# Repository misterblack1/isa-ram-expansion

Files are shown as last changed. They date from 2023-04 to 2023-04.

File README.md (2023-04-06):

# 8-bit ISA RAM expansion board with UMB support

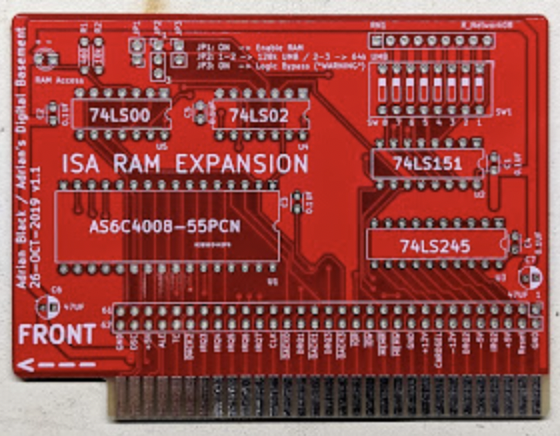
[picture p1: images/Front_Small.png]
PCB Front


This is my simple 8-bit ISA RAM expansion board. I created it to allow me to add UMB memory to a regular XT. It can also bring a 512k or 256k XT up to a full 640k.

- It is simple and easy to build.
- PCB is small so it is inexpensive to have produced.
- No drivers needed. (For conventional memory support)
- Desienged with KiCad, files available here. Free to modify.
- This card only supports conventional memory, no EMS. Extra RAM can be mapped into the high memory space (above 640k) allowing for UMB on XT machines.
- Required parts to build are marked on the PCB silk screen and on the schematic. (Sorry no BOM)

To access UBM, there are various DOS utilities to do this. I have a set of them uploaded in this REPO:
https://github.com/misterblack1/tandy1000ex-hx-ram/tree/master/umb_dos_utils

This card has 512k of 8-bit RAM on it. Therefore, you can map that 512k into the 8088 address space in 128k chunks. (Four chunks.) Use the DIP switches to select which banks are mapped by disabling the extra RAM on the ISA card. Even though you can map the 512k into all of the 1024k of address space in the 8088, please remember the mapping repeats once.

If you imagine the 512k chip is broken up into 4 banks of 128 k. A, B, C and D:

- A -> 0-128k (Lower)
- B -> 128k-256k (Lower)
- C -> 256k-320k (Lower)
- D -> 320k-512k (Lower)
- A -> 512k-640k (Upper)
- B -> 640k-768k (Upper)
- C -> 768k-897k (Upper)
- D -> 869-1024k (Upper)

So when configuring the card to map the 512k RAM into the system memory, you can only use any given bank on time. (Lower OR upper.) So, if you are using lower bank C and D to bring a PC from 256k to 512k total system RAM, you cannot use the upper bank C and D because they are already being used. If you do, the system will crash.

Example:

PC has 256k of RAM installed on the motherboard. This motherboard RAM wil exist from 0k to 256k. 
You want this ISA card to bring the system to 640k conventional. 

Memory map would look like this:

- A -> 0-128k Motherboard
- B -> 128k-256k Motherboard
- C -> 256k-320k ISA RAM card
- D -> 320k-512k ISA RAM card
- A -> 512k-640k ISA RAM card
- B -> 640k-768k used by CGA/MDA card
- C -> 768k-897k Unused
- D -> 869-1024k Unused and System ROMs

So to configure the card, you must configure the DIP switches to disable the ISA RAM card mapping into lower A and B and upper B and D. That way it does not overlap these parts of the system.

Set SW1, SW2, SW6, SW7 and SW8 to ON. The rest should be off. If you try to add UMB memory to upper bank C (768k to 897k) this will not work and cause a crash because you are already using lower bank C to expand from 256k to 320k. The only unused bank on this card would be B -- but you cannot use it for UMB because the 640k-768k range is typically used by the video card. (MDA, CDA, etc.)

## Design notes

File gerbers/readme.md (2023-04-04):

Gerber files to have PCB made with any manufacturer

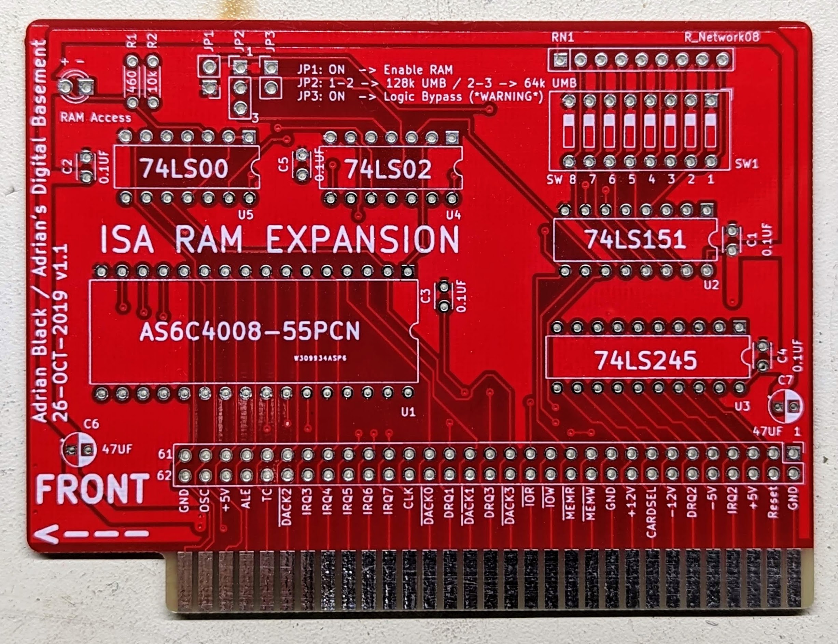
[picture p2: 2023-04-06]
images/PCB_Front.jpg

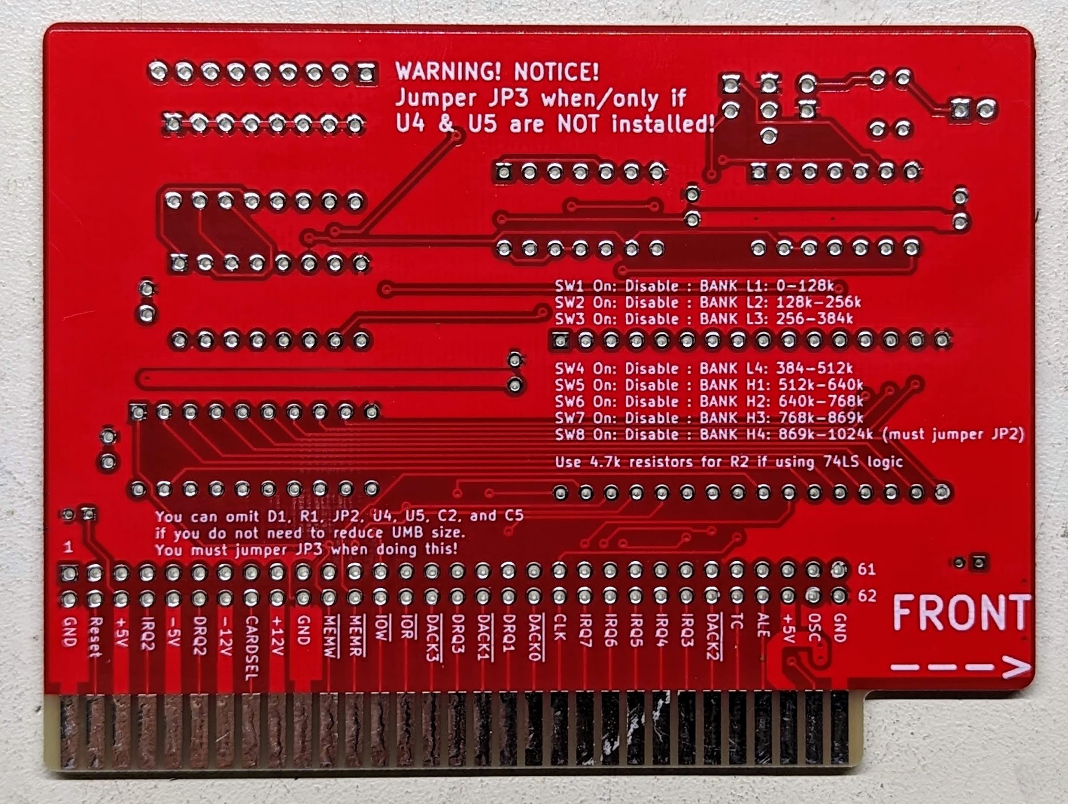
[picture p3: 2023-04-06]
images/PCB_Back.jpg

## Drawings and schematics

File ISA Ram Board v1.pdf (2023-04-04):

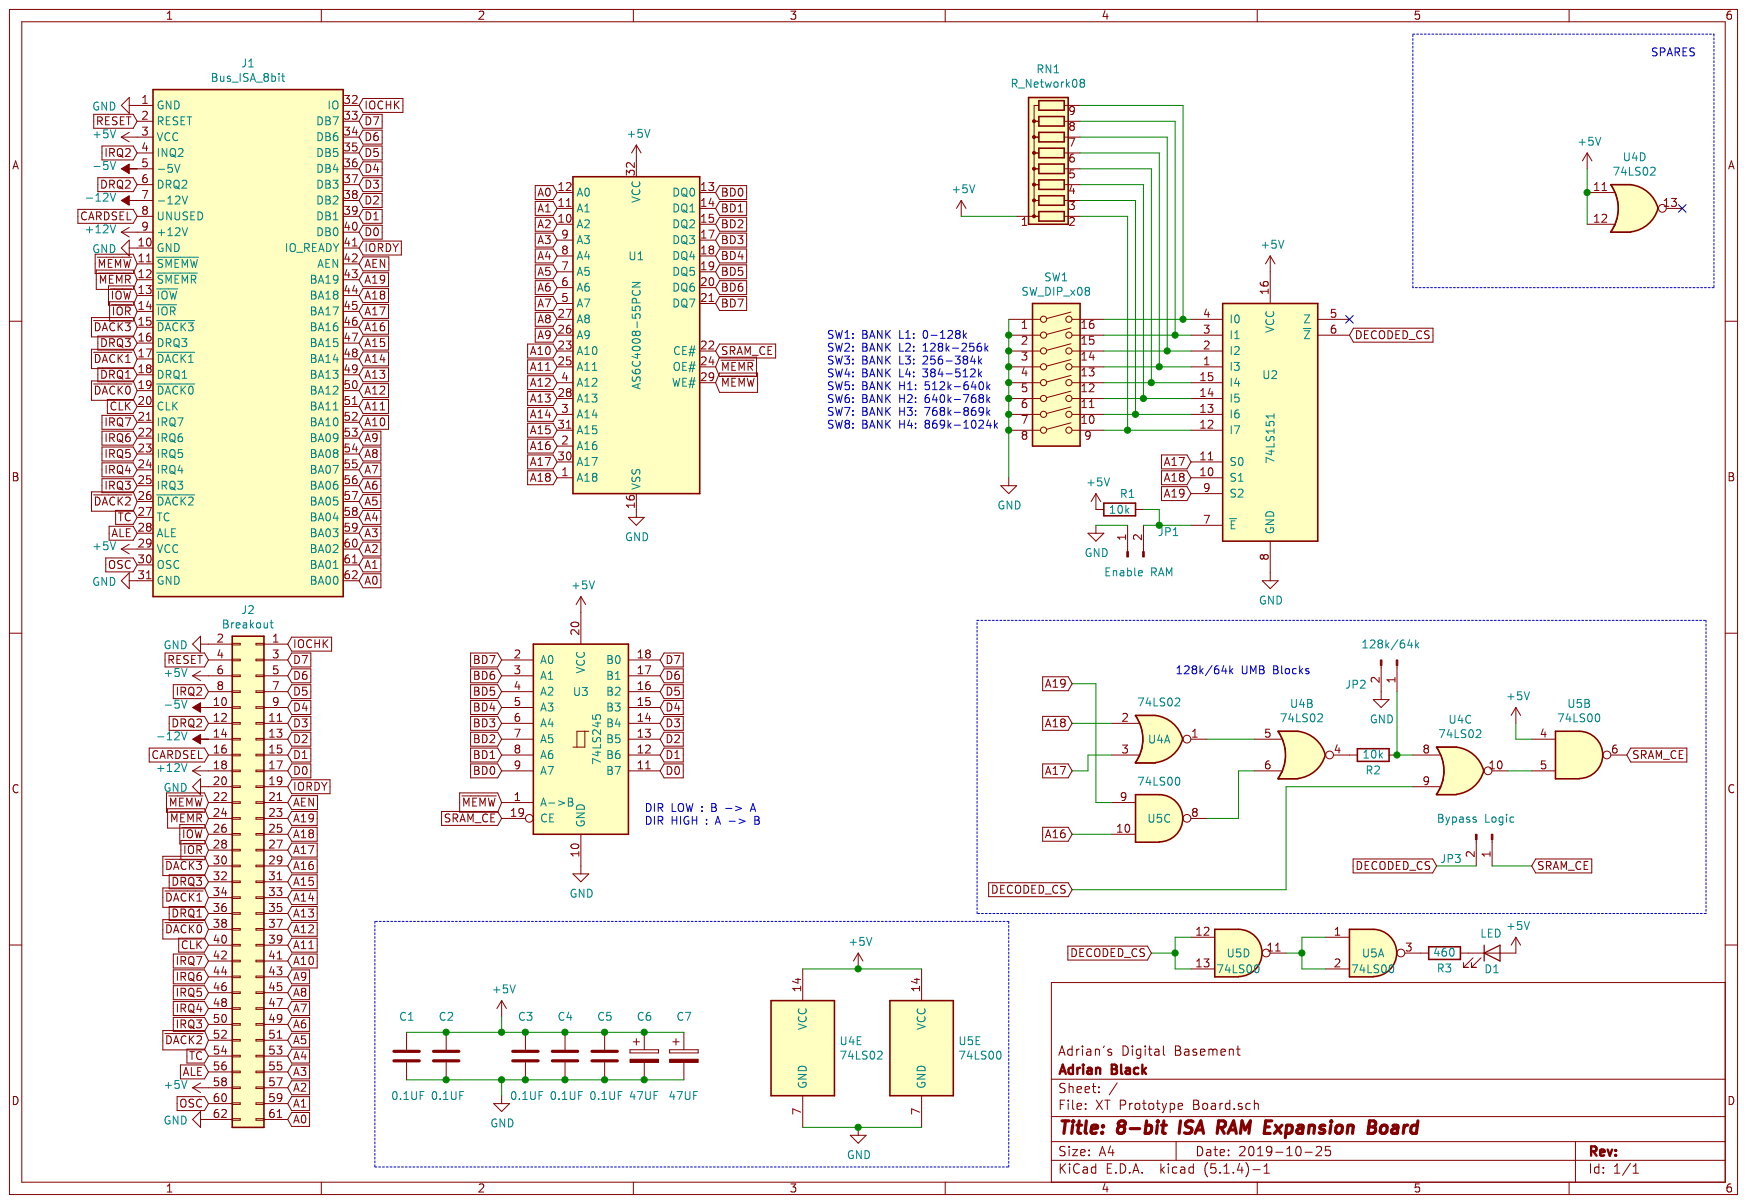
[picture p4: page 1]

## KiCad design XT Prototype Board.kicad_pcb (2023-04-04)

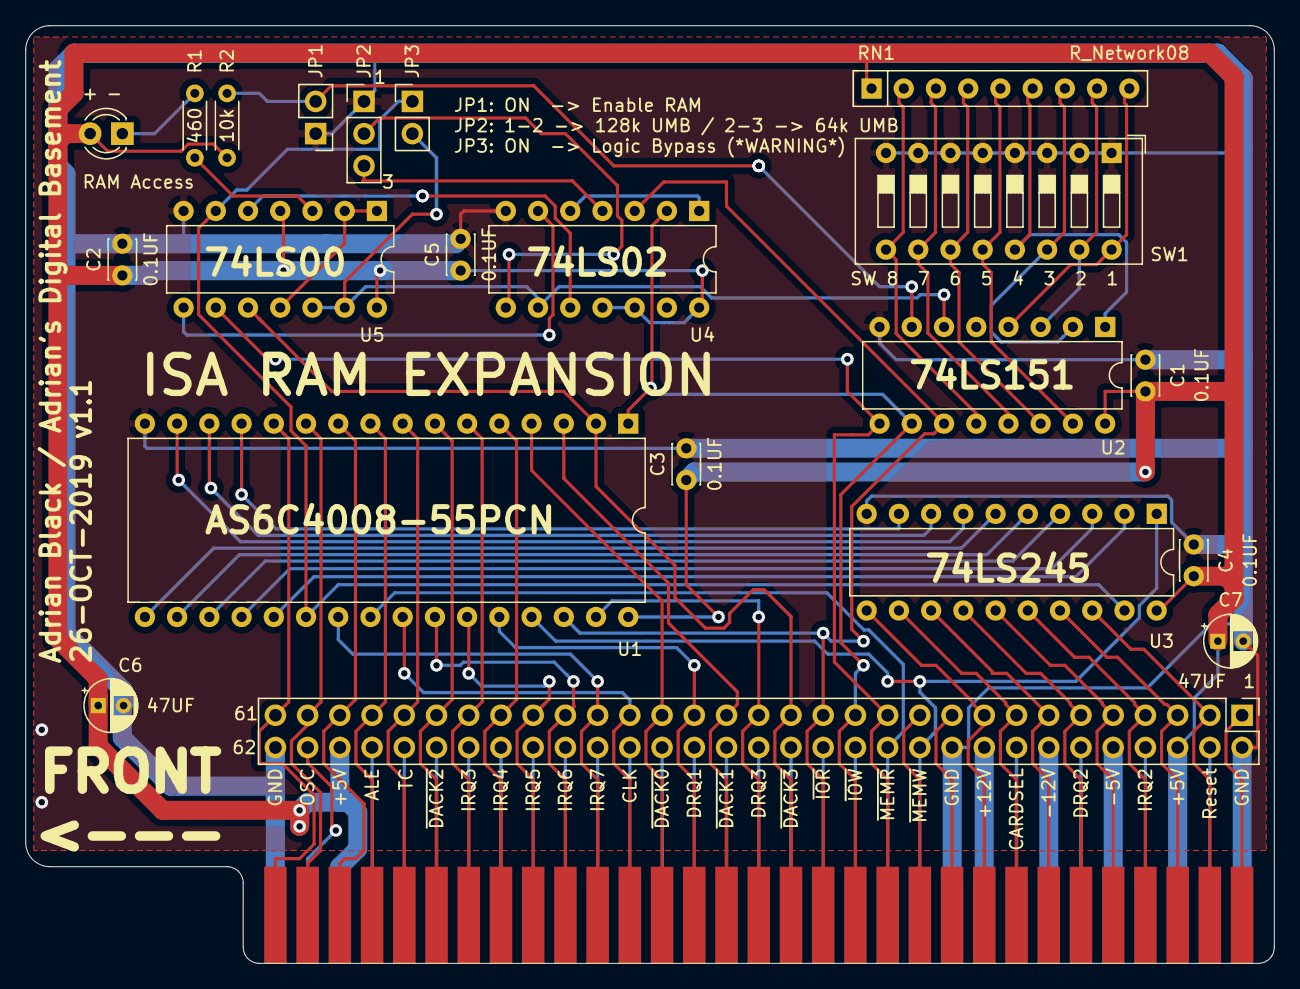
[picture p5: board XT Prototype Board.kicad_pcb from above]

Board: 2 copper layers, 98.4 x 73.9 mm, 22 parts (0 on the bottom side), 86 nets.

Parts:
C1, C2, C3, C4, C5: 0.1UF; C_Disc_D3.0mm_W2.0mm_P2.50mm
C6, C7: 47UF; CP_Radial_D4.0mm_P2.00mm
J1: Bus_ISA_8bit; Conn_Edge_PCB_ISA8
J2: Breakout; PinHeader_2x31_P2.54mm_Vertical
JP1: Enable RAM; PinHeader_1x02_P2.54mm_Vertical
JP2: 128k / 64k UMB; PinHeader_1x03_P2.54mm_Vertical
JP3: Bypass Logic; PinHeader_1x02_P2.54mm_Vertical
R1: 460; R_Axial_DIN0204_L3.6mm_D1.6mm_P5.08mm_Horizontal
R2: 10k; R_Axial_DIN0204_L3.6mm_D1.6mm_P5.08mm_Horizontal
RAM Access: LED; LED_D3.0mm
RN1: R_Network08; R_Array_SIP9
SW1: SW_DIP_x08; SW_DIP_SPSTx08_Slide_9.78x22.5mm_W7.62mm_P2.54mm
U1: AS6C4008-55PCN; DIP-32_W15.24mm
U2: 74LS151; DIP-16_W7.62mm
U3: 74LS245; DIP-20_W7.62mm
U4: 74LS02; DIP-14_W7.62mm
U5: 74LS00; DIP-14_W7.62mm

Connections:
+5V: C1.1, C2.1, C3.1, C4.1, C5.1, C6.1, C7.1, J1.3, J1.29, J2.6, J2.58, R2.2, RAM Access.2, RN1.1, U1.32, U2.16, U3.20, U4.11, U4.12, U4.14, U5.4, U5.14
+12V: J1.9, J2.18
-5V: J1.5, J2.10
-12V: J1.7, J2.14
A0: J1.62, J2.61, U1.12
A1: J1.61, J2.59, U1.11
A2: J1.60, J2.57, U1.10
A3: J1.59, J2.55, U1.9
A4: J1.58, J2.53, U1.8
A5: J1.57, J2.51, U1.7
A6: J1.56, J2.49, U1.6
A7: J1.55, J2.47, U1.5
A8: J1.54, J2.45, U1.27
A9: J1.53, J2.43, U1.26
A10: J1.52, J2.41, U1.23
A11: J1.51, J2.39, U1.25
A12: J1.50, J2.37, U1.4
A13: J1.49, J2.35, U1.28
A14: J1.48, J2.33, U1.3
A15: J1.47, J2.31, U1.31
A16: J1.46, J2.29, U1.2, U5.10
A17: J1.45, J2.27, U1.30, U2.11, U4.3
A18: J1.44, J2.25, U1.1, U2.10, U4.2
A19: J1.43, J2.23, U2.9, U5.9
AEN: J1.42, J2.21
ALE: J1.28, J2.56
BD0: U1.13, U3.9
BD1: U1.14, U3.8
BD2: U1.15, U3.7
BD3: U1.17, U3.6
BD4: U1.18, U3.5
BD5: U1.19, U3.4
BD6: U1.20, U3.3
BD7: U1.21, U3.2
CARDSEL: J1.8, J2.16
CLK: J1.20, J2.40
D0: J1.40, J2.17, U3.11
D1: J1.39, J2.15, U3.12
D2: J1.38, J2.13, U3.13
D3: J1.37, J2.11, U3.14
D4: J1.36, J2.9, U3.15
D5: J1.35, J2.7, U3.16
D6: J1.34, J2.5, U3.17
D7: J1.33, J2.3, U3.18
DECODED_CS: JP3.2, U2.6, U4.9, U5.12, U5.13
DRQ1: J1.18, J2.36
DRQ2: J1.6, J2.12
DRQ3: J1.16, J2.32
GND: C1.2, C2.2, C3.2, C4.2, C5.2, C6.2, C7.2, J1.1, J1.10, J1.31, J2.2, J2.20, J2.62, JP1.1, JP2.1, SW1.1, SW1.2, SW1.3, SW1.4, SW1.5, SW1.6, SW1.7, SW1.8, U1.16, U2.8, U3.10, U4.7, U5.7
IOCHK: J1.32, J2.1
IORDY: J1.41, J2.19
IRQ2: J1.4, J2.8
IRQ3: J1.25, J2.50
IRQ4: J1.24, J2.48
IRQ5: J1.23, J2.46
IRQ6: J1.22, J2.44
IRQ7: J1.21, J2.42
unnamed: R1.2, RAM Access.1
unnamed: JP1.2, R2.1, U2.7
unnamed: JP2.2, U4.8
unnamed: JP2.3, U4.4
unnamed: R1.1, U5.3
unnamed: RN1.2, SW1.9, U2.12
unnamed: RN1.3, SW1.10, U2.13
unnamed: RN1.4, SW1.11, U2.14
unnamed: RN1.5, SW1.12, U2.15
unnamed: RN1.6, SW1.13, U2.1
unnamed: RN1.7, SW1.14, U2.2
unnamed: RN1.8, SW1.15, U2.3
unnamed: RN1.9, SW1.16, U2.4
unnamed: U4.1, U4.5
unnamed: U4.6, U5.8
unnamed: U4.10, U5.5
unnamed: U5.1, U5.2, U5.11
OSC: J1.30, J2.60
RESET: J1.2, J2.4
SRAM_CE: JP3.1, U1.22, U3.19, U5.6
TC: J1.27, J2.54
~DACK0: J1.19, J2.38
~DACK1: J1.17, J2.34
~DACK2: J1.26, J2.52
~DACK3: J1.15, J2.30
~IOR: J1.14, J2.28
~IOW: J1.13, J2.26
~MEMR: J1.12, J2.24, U1.24
~MEMW: J1.11, J2.22, U1.29, U3.1

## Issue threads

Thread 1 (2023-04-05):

No BOM

inbarraz, 2023-04-05:
Perhaps I missed it, but is there a BOM anywhere? I'd like to build this.

misterblack1, 2023-04-06:
All the required parts are marked on the silk screen of the PCB itself, and also on the schematic. Sorry there's no table form of the BOM.

Closed 2023-04-06.

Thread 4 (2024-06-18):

UMB not showing up on AT machine

KenjiUmino, 2024-06-18:
Hi Adrian, you are probably quite busy at the moment, but can you help me out?

I finally got around to building your isa ram expansion card and put it in my IBM 5170 which, as you know, has only 512k on board and no extra empty sockets on the board to put some more in.

I know that is an AT machine and the card is meant for XT machines but since (AFAIK) no one came up with a similar open source ram card for the 16 bit isa slot and original AT ram expansion cards from back in the day are too expensive for my taste, I thought I'd give this a try.

Many games and applications give me a "not enough memory" complaint, some will start anyway just to crash or lock up shortly after - so I think adding more memory, even if it is slow, might at least solve the crashing.

The idea was to expand the conventional memory from 512k to 640k and maybe have some more between the VGA (640-768k) and the BIOS (960-1024), although, since the VGA card also has the video BIOS starting right after 768k and I have an XT-IDE rom somewhere after that, all I'd be able to get out of that expansion card would be the last 64k block before the BIOS.

I probably should not load DOS or anything speed sensitive into this high block, but I may shift some less important stuff there to free up more conventional memory (like that scan.sys driver that a certain photo editing application wants to have, even when there is no scanner connected).

The card is configured like this: DIP switches #5 and #8 UP (OFF) and JP2 set to 2-3 (I assume that will chop the topmost 128k chunk enabled by switch #8 in half to not conflict with the BIOS rom - correct?)

Expanding the conventional memory to 640k works already (the memory count at boot up slows down significantly after 512k, as expected) but the upper 64k block does not show up.

- checkit does not see it
- test!umb.exe does not see it (it does only see the video ram)
- loading use!umb.sys at startup does produce text output on boot but DOS still reports no upper memory

What am I missing?

Edit:
I think I figured it out.
While searching the Web for this particular issue did not bring up anything useful, I found a possible answer yesterday when I stumbled upon another random "let's build a 16 bit memory board" forum thread that went nowhere - it contained 8 pages of discussion but went silent in May 2022 - too bad.

However, there was a bit of back and forth about how to handle MEMCS16# (also called M16*) and that gave me some Information I was missing.

That MEMCS16# signal is a way for an AT system to detect wether it is talking to a "legacy" device with 8 bit data bus or a true 16 bit one.

The thing is that MEMCS16# can only be set for a whole 128k chunk at a time.

That would explain why adding a whole 128k block of 8 bit memory between 512k and 640k works while adding 64k before the BIOS (which is certainly 16 bit) does not - the mainboard asserts MEMCS16# for the topmost 128k chunk to access the 64k BIOS rom and the 64k of 8 bit RAM gets ignored because it is read as garbage

Closed 2024-06-19.

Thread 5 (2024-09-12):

Value of the resistorpack is not on the PCB

JoopIdema, 2024-09-12:
The value of the resistorpack is not marked on the PCB. I assume 4k7 or 10k would be ok?

sfambach, 2025-02-22:
On the back site lower right corner is 4k7 mentioned if 74LS is used

JoopIdema, 2025-02-22:
No, that is the value for R2, not the value for the resistor-network RN1. I used 10K for RN1 and it worked fine.

sfambach, 2025-09-26:
Ok I used 4k7 worked, too, but maybe it explaines some trouble I had. Some words from the master would be good ;)

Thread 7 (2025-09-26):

Confused about the DIP switches

sfambach, 2025-09-26:
Hi Adrian Black and others

I am a little confused about the dip switches, from that what I read, the dipswitch should be turned 180 deg. Then on and off and also 1-8 would fit, or am I mistaken?

BR

SteFam76 from Germany
